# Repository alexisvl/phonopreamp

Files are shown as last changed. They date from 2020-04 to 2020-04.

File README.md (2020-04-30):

# PA1-P06 phono preamplifier

This is my spin on the well known [Elliott Sound Products] "Project 06" phono preamp, with integrated power supply, a couple modifications, and an acrylic sandwich enclosure.

[LICENSE] NOTE: The original ESP P06 is not licensed for reuse in any way. This variant uses only the filter chain topology and component values, neither of which are directly copyrightable, but **please** respect the original designer's (and my) wishes: my version is licensed CC BY-NC-SA, that is the most restrictive of all Creative Commons licenses and forbids commercial use even if you were to follow all the usual open-source rules! Both ESP and I are explicitly requesting you not make money off this design. It's not terribly hard to figure out how to implement the RIAA curves for yourself if you want a commercial product. Don't mooch, filthy capitalist pigs.

The CAD files were created with a development build of KiCad from April 2020; a release build may not load them properly.

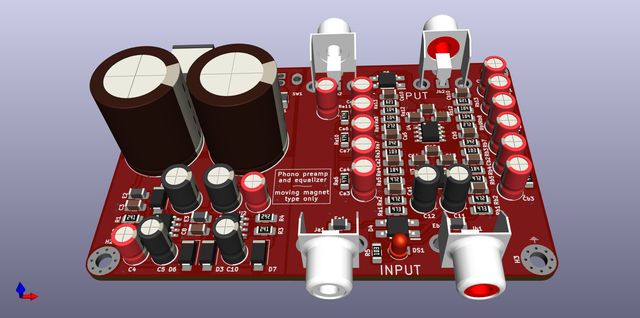
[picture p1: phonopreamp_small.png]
3D render
[](../master/phonopreamp.png)

- [Schematic]
- [BOM] in Digi-Key bulk add format

## Revision B

This repository includes a Revision B, which I have not yet actually built. See the [changelog] for more information.

## Gerbers

Gerbers currently don't exist in this repository. Recent KiCad builds have had a bug with Gerber export that bit me when I was having this board made and I don't want to go posting files until I'm more confident. Generate yourself, at your own risk.

## Assembly tips

- The mounting screw near the input jacks is meant to be the anchor point for a ground wire. I added a solder lug and heatshrink to the phono ground lead, then put the lug between screw and washer in that corner.
- Build the board as a sandwich: M3×0.5 screw, through nylon or fiber washer (I used [RPC10339-ND]), through acrylic base plate, into short standoff, through PCB, into long standoff (see BOM). From the top, M3×0.5 screw, through washer, through acrylic top plate, into standoff. On the ground terminal corner, the ground lug goes between the top screw and washer.
    - Washers are necessary to prevent _cracking_ the acrylic (I'm not just being picky about scratches), and should be soft washers. These will give slightly if the screws are over-tightened, both preventing excessive pressure on the acrylic, as well as compressing to lock the screws in place better.
    - Short standoffs are omitted from BOM because I ordered the wrong ones and improvized with a couple nuts — I don't have a part number. They should be about 5mm long.
- The PPS film capacitors are, to be polite, a complete bitch to stuff. They're basically unsolderable as they melt easily, and are moisture sensitive too. The method I used is: assemble entire board except these using water soluble flux; wash very well to keep clean. Carefully spot-solder film capacitors with no-clean flux, low temperature, quickly, being careful not to touch the sides with the iron, squish with tweezers, or keep hot too long. Do not wash.
    - If you don't care about cleaning the flux, just use no-clean for the whole board and resist any temptation to clean it.

### Assembled stack:

```
|>----    |    ##    [===]---    ##    [===============]    ##    |          -----<|
               ##                ##                         ##
               ##                ##                         ##
               ##                ##                         ##
               ##                ##                         ##
               ##                ##                         ##
|>----    |    ##    [===]---    ##    [===============]    ##    |    ||    -----<|

^         ^    ^     ^           ^     ^                    ^     ^    ^     ^
|         |    |     |           |     |                    |     |    |     M3×0.5 screws
|         |    |     |           |     |                    |     |    ground lug (input corner only)
|         |    |     |           |     |                    |     nylon washers
|         |    |     |           |     |                    top acrylic plate
|         |    |     |           PCB   long F-F standoffs
|         |    |     short F-M standoffs
|         |    bottom acrylic plate
|         nylon washers
M3×0.5 screws
```

[Elliott Sound Products]: http://sound-au.com/project06.htm
[Schematic]: ../master/phonopreamp.pdf
[LICENSE]: ../master/COPYING
[changelog]: ../master/CHANGELOG
[render_small]: ../master/phonopreamp_small.png
[BOM]: ../master/phonopreamp/bom.txt
[RPC10339-ND]: https://www.digikey.com/product-detail/en/essentra-components/16M03080080/RPC10339-ND/10299235

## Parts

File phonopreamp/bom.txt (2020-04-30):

Digi-Key compatible BOM in minimum quantities.

LED is excluded!

4,1655-1504-1-ND
3,1655-1817-1-ND
2,2019-RN73R2BTTD4702B25CT-ND
1,237-1887-ND
2,296-35279-1-ND
4,311-2953-1-ND
2,311-2967-1-ND
2,311-4433-1-ND
4,36-24438-ND
4,399-15740-ND
8,399-C1206C104K5RAC7800CT-ND
1,563-1558-ND
2,565-3924-ND
12,732-9268-1-ND
2,732-9587-1-ND
1,CP-063AH-ND
2,CP-1401-ND
2,CP-1402-ND
1,LM317LMX/NOPBCT-ND
1,LM337LMX/NOPBCT-ND
5,MH3261-601YCT-ND
2,P14435-ND
6,PCF1181CT-ND
3,RMCF1206FT10K0CT-ND
4,RMCF1206FT240RCT-ND
2,RMCF1206FT2K43CT-ND
2,RMCF1206FT2K70CT-ND
2,RMCF1206FT3K40CT-ND
4,RMCF1206FT4K70CT-ND
2,RMCF1206FT620RCT-ND
6,RMCF1206JT470KCT-ND

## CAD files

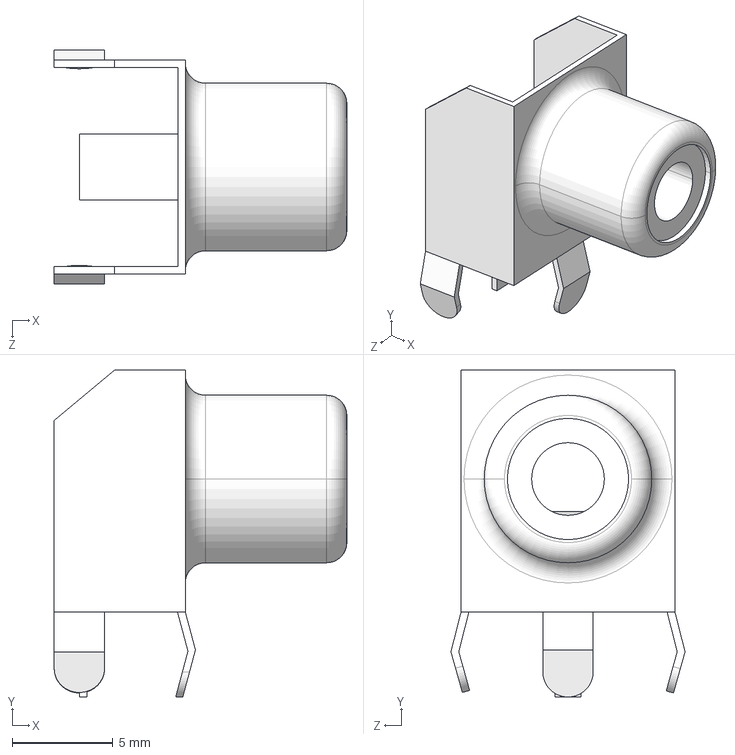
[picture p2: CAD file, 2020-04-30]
phonopreamp/3d/CUI_DEVICES_RCJ-013.step
14.5 x 16.2 x 11.6 mm

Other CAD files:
phonopreamp/3d/CUI_DEVICES_RCJ-012.step

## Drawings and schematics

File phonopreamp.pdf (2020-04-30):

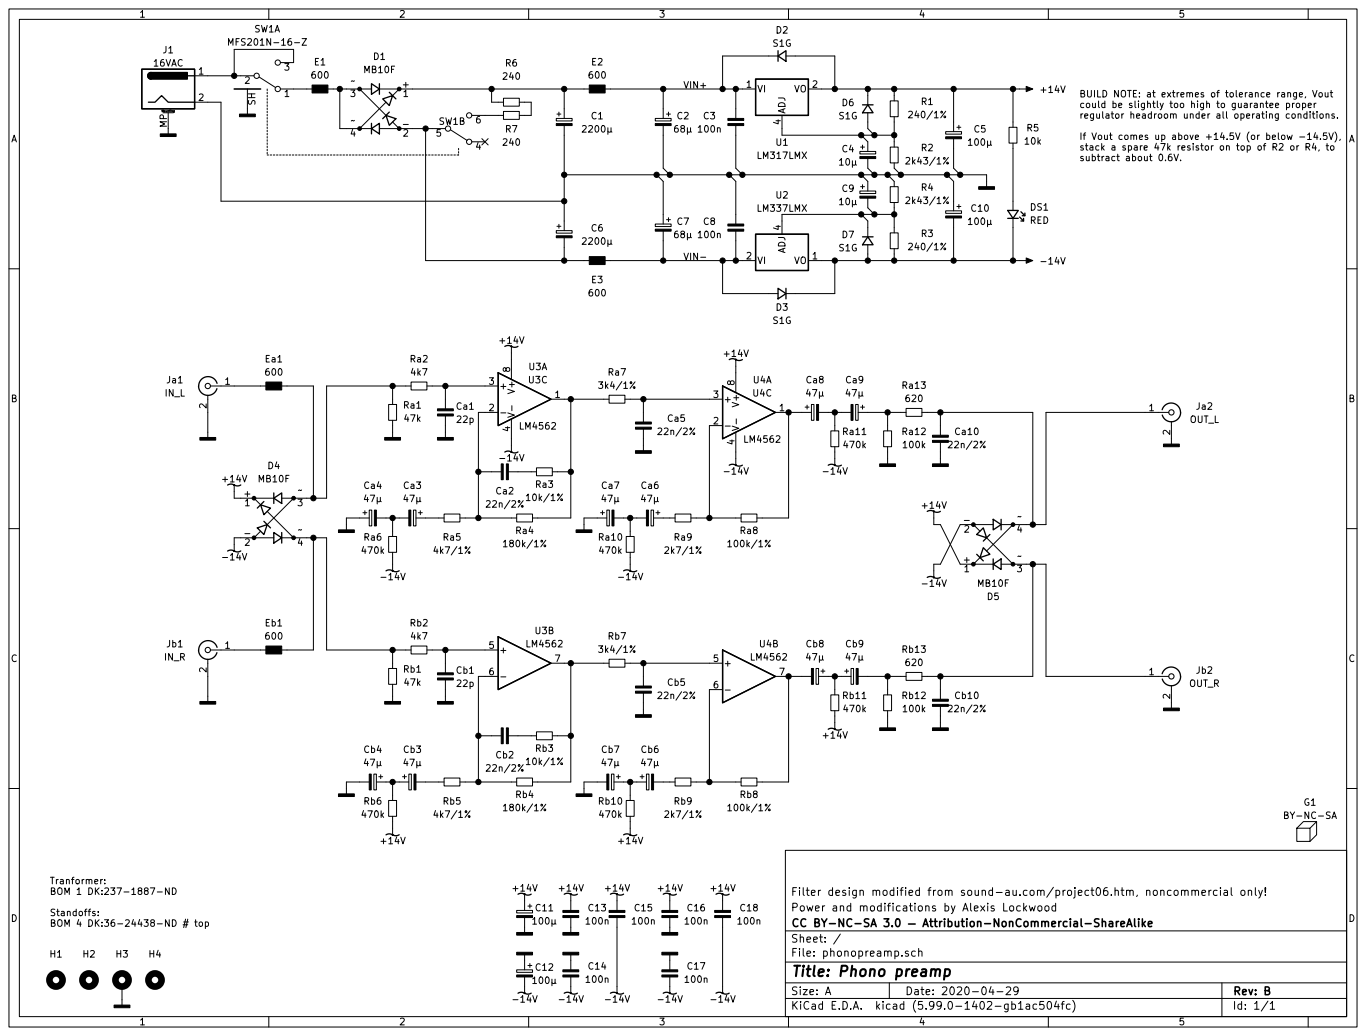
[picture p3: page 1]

BUILD NOTE: at extremes of tolerance range, Vout
could be slightly too high to guarantee proper
regulator headroom under all operating conditions.

If Vout comes up above +14.5V (or below -14.5V),
stack a spare 47k resistor on top of R2 or R4, to
subtract about 0.6V.

Tranformer: BOM 1 DK:237-1887-ND

Filter design modified from sound-au.com/project06.htm, noncommercial only! +14V C15

File: phonopreamp.sch Sheet: / CC BY-NC-SA 3.0 Attribution-NonCommercial-ShareAlike Power and modifications by Alexis Lockwood

Standoffs: BOM 4 DK:36-24438-ND # top

Id: 1/1 Title: Phono preamp

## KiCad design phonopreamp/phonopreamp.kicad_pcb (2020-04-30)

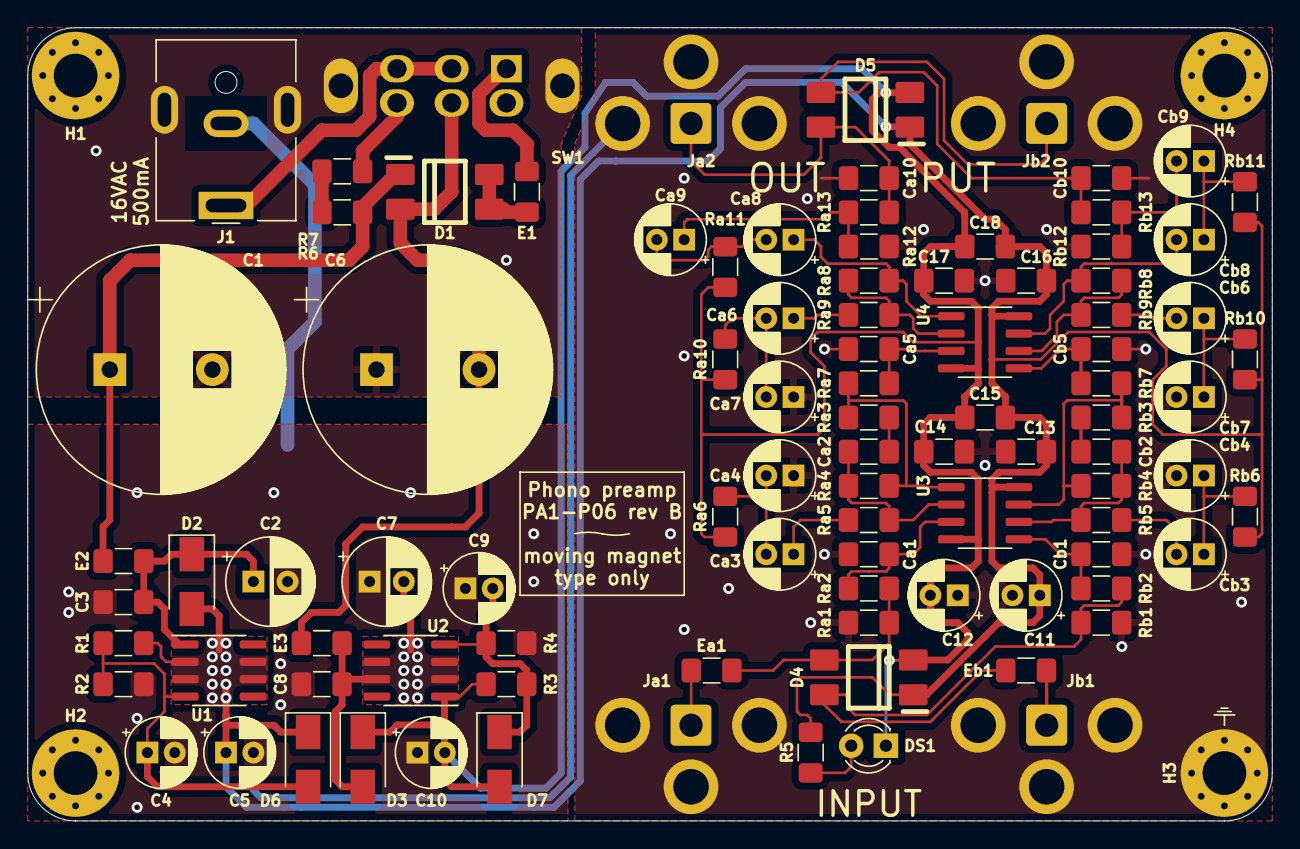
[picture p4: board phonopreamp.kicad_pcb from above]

Board: 2 copper layers, 91.0 x 58.0 mm, 99 parts (1 on the bottom side), 47 nets.

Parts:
C1, C6: 2200µ; CP_Radial_D18.0mm_P7.50mm
C2, C7: 68µ; CP_Radial_D6.3mm_P2.50mm
C3, C8, C13, C14, C15, C16, C17, C18: 100n; C_1206_3216Metric_Pad1.42x1.75mm_HandSolder
C4, C9: 10µ; CP_Radial_D5.0mm_P2.00mm
C5, C10, C11, C12: 100µ; CP_Radial_D5.0mm_P2.00mm
Ca1: 22p; C_1206_3216Metric_Pad1.42x1.75mm_HandSolder
Ca2, Ca5, Ca10: 22n/2%; C_1206_3216Metric_Pad1.42x1.75mm_HandSolder
Ca3, Ca4, Ca6, Ca7, Ca8, Ca9: 47µ; CP_Radial_D5.0mm_P2.00mm
Cb1: 22p; C_1206_3216Metric_Pad1.42x1.75mm_HandSolder
Cb2, Cb5, Cb10: 22n/2%; C_1206_3216Metric_Pad1.42x1.75mm_HandSolder
Cb3, Cb4, Cb6, Cb7, Cb8, Cb9: 47µ; CP_Radial_D5.0mm_P2.00mm
D1, D4, D5: MB10F; MBxS
D2, D3, D6, D7: S1G; D_SMA
DS1: RED; LED_D3.0mm
E1, E2, E3: 600; L_1206_3216Metric_Pad1.42x1.75mm_HandSolder
Ea1: 600; L_1206_3216Metric_Pad1.42x1.75mm_HandSolder
Eb1: 600; L_1206_3216Metric_Pad1.42x1.75mm_HandSolder
G1: BY-NC-SA; Logo_silk_CC-BY-NC-SA_10x3.6mm
H1, H2, H3, H4: MountingHole; MountingHole_3.2mm_M3_Pad_Via
J1: 16VAC; BarrelJack_CUI_PJ-063AH_Horizontal
Ja1: IN_L; RCJ-01x
Ja2: OUT_L; RCJ-01x
Jb1: IN_R; RCJ-01x
Jb2: OUT_R; RCJ-01x
R1, R3: 240/1%; R_1206_3216Metric_Pad1.42x1.75mm_HandSolder
R2, R4: 2k43/1%; R_1206_3216Metric_Pad1.42x1.75mm_HandSolder
R5: 10k; R_1206_3216Metric_Pad1.42x1.75mm_HandSolder
R6, R7: 240; R_1206_3216Metric_Pad1.42x1.75mm_HandSolder
Ra1: 47k; R_1206_3216Metric_Pad1.42x1.75mm_HandSolder
Ra2: 4k7; R_1206_3216Metric_Pad1.42x1.75mm_HandSolder
Ra3: 10k/1%; R_1206_3216Metric_Pad1.42x1.75mm_HandSolder
Ra4: 180k/1%; R_1206_3216Metric_Pad1.42x1.75mm_HandSolder
Ra5: 4k7/1%; R_1206_3216Metric_Pad1.42x1.75mm_HandSolder
Ra6, Ra10, Ra11: 470k; R_1206_3216Metric_Pad1.42x1.75mm_HandSolder
Ra7: 3k4/1%; R_1206_3216Metric_Pad1.42x1.75mm_HandSolder
Ra8: 100k/1%; R_1206_3216Metric_Pad1.42x1.75mm_HandSolder
Ra9: 2k7/1%; R_1206_3216Metric_Pad1.42x1.75mm_HandSolder
Ra12: 100k; R_1206_3216Metric_Pad1.42x1.75mm_HandSolder
Ra13: 620; R_1206_3216Metric_Pad1.42x1.75mm_HandSolder
Rb1: 47k; R_1206_3216Metric_Pad1.42x1.75mm_HandSolder
Rb2: 4k7; R_1206_3216Metric_Pad1.42x1.75mm_HandSolder
Rb3: 10k/1%; R_1206_3216Metric_Pad1.42x1.75mm_HandSolder
Rb4: 180k/1%; R_1206_3216Metric_Pad1.42x1.75mm_HandSolder
Rb5: 4k7/1%; R_1206_3216Metric_Pad1.42x1.75mm_HandSolder
Rb6, Rb10, Rb11: 470k; R_1206_3216Metric_Pad1.42x1.75mm_HandSolder
Rb7: 3k4/1%; R_1206_3216Metric_Pad1.42x1.75mm_HandSolder
Rb8: 100k/1%; R_1206_3216Metric_Pad1.42x1.75mm_HandSolder
Rb9: 2k7/1%; R_1206_3216Metric_Pad1.42x1.75mm_HandSolder
Rb12: 100k; R_1206_3216Metric_Pad1.42x1.75mm_HandSolder
Rb13: 620; R_1206_3216Metric_Pad1.42x1.75mm_HandSolder
SW1: MFS201N-16-Z
U1: LM317LMX; SOIC-8_3.9x4.9mm_P1.27mm
U2: LM337LMX; SOIC-8_3.9x4.9mm_P1.27mm
U3, U4: LM4562; SOIC-8_3.9x4.9mm_P1.27mm

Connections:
+14V: C5.1, C11.1, C13.1, C15.1, C16.1, C18.1, D2.2 (A), D4.1 (+), D5.1 (+), D6.1 (K), R1.2, R5.2, Rb6.1, Rb10.1, Rb11.1, U1.2 (VO), U1.3 (VO), U1.6 (VO), U1.7 (VO), U3.8 (V+), U4.8 (V+)
-14V: C10.2, C12.2, C14.1, C15.2, C17.1, C18.2, D3.1 (K), D4.2 (-), D5.2 (-), D7.2 (A), DS1.1 (K), R3.1, Ra6.1, Ra10.1, Ra11.1, U2.1 (VO), U3.4 (V-), U4.4 (V-)
/VIN+: C2.1, C3.1, D2.1 (K), E2.2, U1.1 (VI)
/VIN-: C7.2, C8.2, D3.2 (A), E3.2, U2.2 (VI), U2.3 (VI), U2.6 (VI), U2.7 (VI)
GND: C1.2, C2.2, C3.2, C4.2, C5.2, C6.1, C7.1, C8.1, C9.1, C10.1, C11.2, C12.1, C13.2, C14.2, C16.2, C17.2, Ca1.2, Ca4.1, Ca5.1, Ca7.1, Ca10.1, Cb1.2, Cb4.2, Cb5.1, Cb7.2, Cb10.1, H3.1, J1.2, J1.MP (MountPin), Ja1.2 (Ext), Ja2.2 (Ext), Jb1.2 (Ext), Jb2.2 (Ext), R2.1, R4.2, Ra1.1, Ra12.1, Rb1.1, Rb12.1, SW1.SH
unnamed: C1.1, D1.1 (+), E2.1, R6.2
unnamed: C4.1, D6.2 (A), R1.1, R2.2, U1.4 (ADJ)
unnamed: C6.2, D1.2 (-), E3.1, SW1.5 (B)
unnamed: C9.2, D7.1 (K), R3.2, R4.1, U2.4 (ADJ)
unnamed: Ca1.1, Ra2.2, U3.3 (+)
unnamed: Ca2.1, Ra4.1, Ra5.2, U3.2 (-)
unnamed: Ca2.2, Ra3.1
unnamed: Ca3.1, Ra5.1
unnamed: Ca3.2, Ca4.2, Ra6.2
unnamed: Ca5.2, Ra7.2, U4.3 (+)
unnamed: Ca6.1, Ra9.1
unnamed: Ca6.2, Ca7.2, Ra10.2
unnamed: Ca8.1, Ra8.2, U4.1
unnamed: Ca8.2, Ca9.2, Ra11.2
unnamed: Ca9.1, Ra12.2, Ra13.1
unnamed: Ca10.2, D5.4 (~~), Ja2.1 (In), Ra13.2
unnamed: Cb1.1, Rb2.2, U3.5 (+)
unnamed: Cb2.1, Rb4.1, Rb5.2, U3.6 (-)
unnamed: Cb2.2, Rb3.1
unnamed: Cb3.1, Cb4.1, Rb6.2
unnamed: Cb3.2, Rb5.1
unnamed: Cb5.2, Rb7.2, U4.5 (+)
unnamed: Cb6.1, Cb7.1, Rb10.2
unnamed: Cb6.2, Rb9.1
unnamed: Cb8.1, Cb9.1, Rb11.2
unnamed: Cb8.2, Rb8.2, U4.7
unnamed: Cb9.2, Rb12.2, Rb13.1
unnamed: Cb10.2, D5.3 (~~), Jb2.1 (In), Rb13.2
unnamed: D1.3 (~~), D1.4 (~~), E1.2
unnamed: D4.3 (~~), Ea1.2, Ra1.2, Ra2.1
unnamed: D4.4 (~~), Eb1.2, Rb1.2, Rb2.1
unnamed: DS1.2 (A), R5.1
unnamed: E1.1, SW1.1 (A)
unnamed: Ea1.1, Ja1.1 (In)
unnamed: Eb1.1, Jb1.1 (In)
unnamed: J1.1, SW1.2 (B), SW1.3 (C)
unnamed: R6.1, R7.1
unnamed: R7.2, SW1.6 (C)
unnamed: Ra3.2, Ra4.2, Ra7.1, U3.1
unnamed: Ra8.1, Ra9.2, U4.2 (-)
unnamed: Rb3.2, Rb4.2, Rb7.1, U3.7
unnamed: Rb8.1, Rb9.2, U4.6 (-)

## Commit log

2020-04-30 Release revision B
    [phonopreamp.kicad_pcb, phonopreamp.sch]
2020-04-30 Add gerbers note
2020-04-30 Update BOM for rev B
2020-04-30 Add assembly tips
